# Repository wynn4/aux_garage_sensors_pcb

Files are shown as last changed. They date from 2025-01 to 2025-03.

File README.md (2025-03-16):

# *GarageGateGuard*
## About
This project contains KiCad 8.0 files and all supporting information needed for you to build your own *GarageGateGuard* PCB to protect the liftgate of your vehicle from having the garage door accidentally closed on it. The *GarageGateGuard* PCB enables you to add an auxiliary pair of infrared sensors to your garage door opening. When the auxiliary sensors are blocked (e.g., by your car's liftgate), power to the infrared transmitter of your opener's primary sensor pair is interrupted--emulating a blockage condition and stopping your opener from closing the door. Regular safety operation of your primary sensors is still maintained.

The PCB is built around a circuit presented by [@0033mer](https://youtube.com/@0033mer?si=xY0d-Dty4cxYaAsI) in a his "Garage Door Safety Sensors" [video](https://youtu.be/CdpjvQUqqL8?si=sJUc2Y0D_GqsPqLC) where he shows how to decode the output of the infrared receiver to determine if the beam from the transmitter is being received or not. In this PCB design, the decoded signal is used to control an NMOS switch which is wired up to control the ON-state of the garage opener's primary infrared transmitter. Full details can be seen in the included schematic and wiring diagram.

## Operation
For the auxiliary sensors, the PCB is designed to use a pair of 6V "universal" garage door safety sensors and has been validated using [these sensors](https://a.co/d/aTHSjK9) from Amazon. In theory the name-brand sensors from LiftMaster, Chamberlain, etc., should also work, but none of these have been tested. Because the system's "interface" with the existing garage door opener is so simple (i.e., just interrupting the ground connection to the opener's existing infrared transmitter), it should work with virtually any opener that has safety sensors powered by DC voltage under 40V (this is the Drain-Source voltage limit of the NMOS). The PCB reqires 6VDC supplied via J1 (see BOM for recommended power supply) and the PWR LED will illuminate to indicate the board is powered-on. When the auxiliary sensors (TXB and RXB) are not within line-of-sight of each other, the BLK (i.e., "blocked") LED will also illuminate. For the PCB to function as designed, a pin-jumper (see BOM) must be placed in the ACT (i.e., "active") position on JP1. If the PCB were to fail, or begin to malfunction, original operation of your garage door could be quickly restored by simply moving the jumper to the BYP (i.e., "bypass") position.

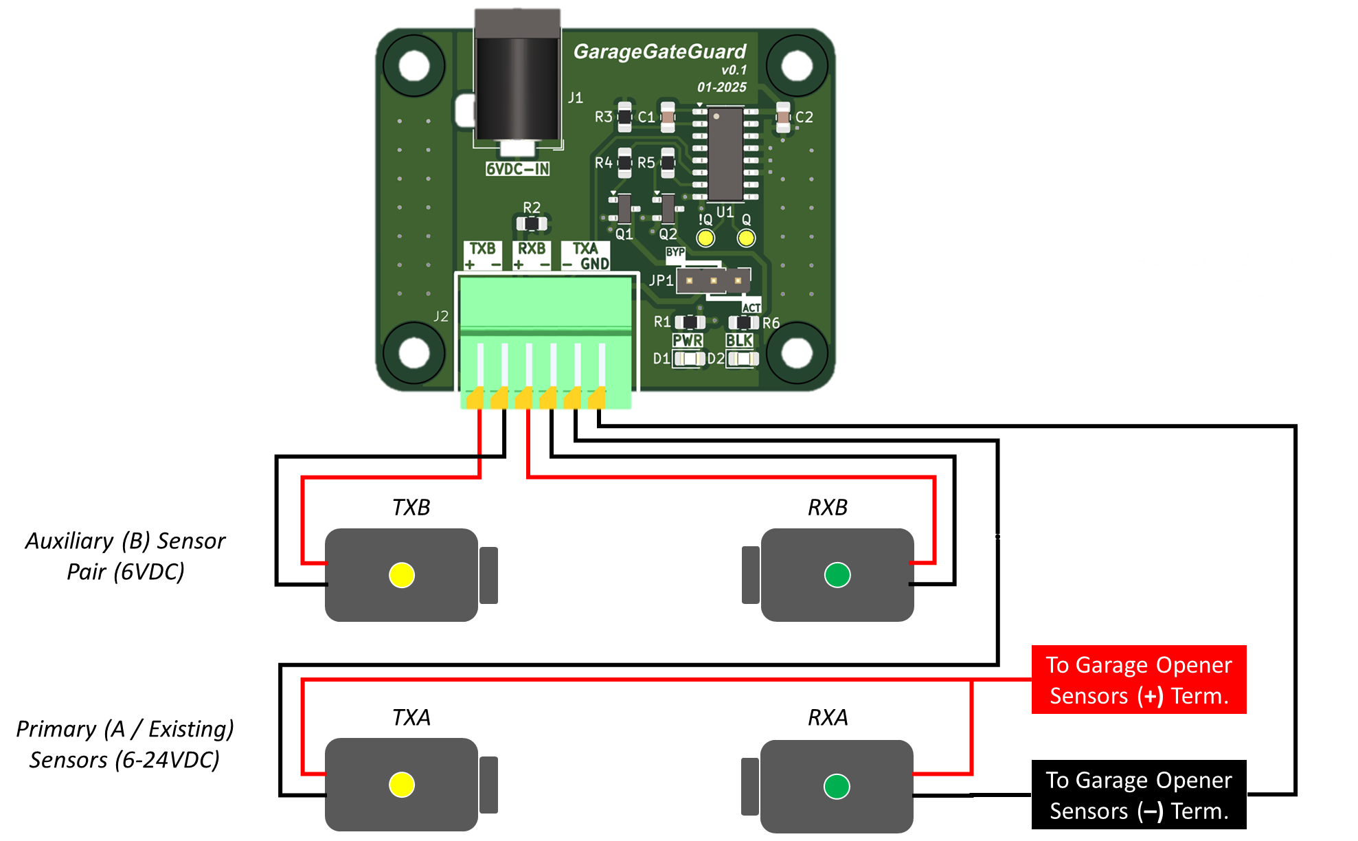
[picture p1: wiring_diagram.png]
wiring_diagram


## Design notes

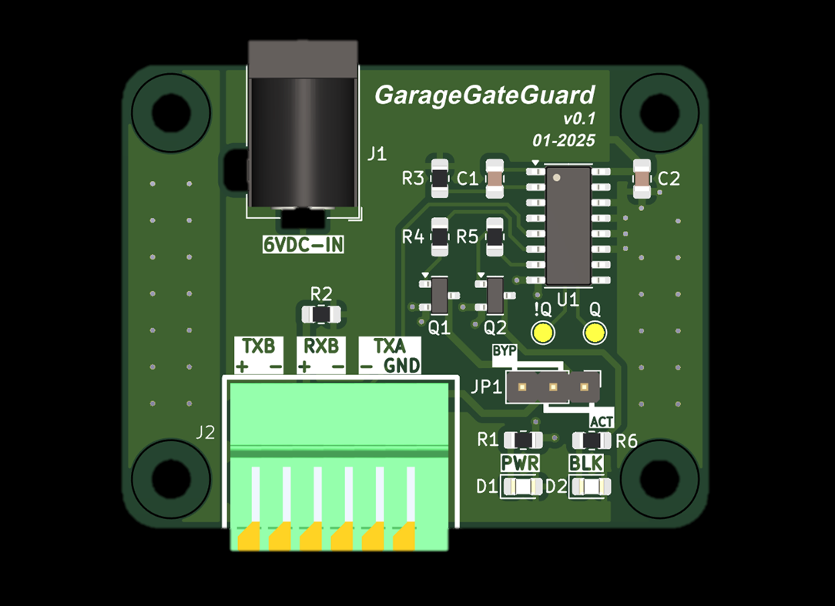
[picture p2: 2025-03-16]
render_v01.png

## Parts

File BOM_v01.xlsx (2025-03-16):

REF | MFR | MPN | QTY | DNI
C1, C2 | Samsung Electro-Mechanics | CL21B104KBCNNNC | 2 | 0
D1, D2 | Würth Elektronik | 150080AS75000 | 2 | 0
J1 | Same Sky (Formerly CUI Devices) | PJ-102AH | 1 | 0
J2 | Same Sky (Formerly CUI Devices) | TBL003-254-06GR-2OR | 1 | 0
JP1 | Würth Elektronik | 61300311121 | 1 | 0
Q1, Q2 | Infineon Technologies | IRLML0040TRPBF | 2 | 0
R1, R4-R6 | Stackpole Electronics Inc | RNCP0805FTD1K00 | 4 | 0
R2 | Panasonic Electronic Components | ERJ-P06J151V | 1 | 0
R3 | YAGEO | RC0805FR-07100KL | 1 | 0
U1 | Texas Instruments | CD14538BM96 | 1 | 0
PCB Post-Manufacturing Accessories
JP1-JP | Sullins Connector Solutions | QPC02SXGN-RC | 1 | 1
6V-PSU | XP Power | VEL05US060-US-JA | 1 | 1

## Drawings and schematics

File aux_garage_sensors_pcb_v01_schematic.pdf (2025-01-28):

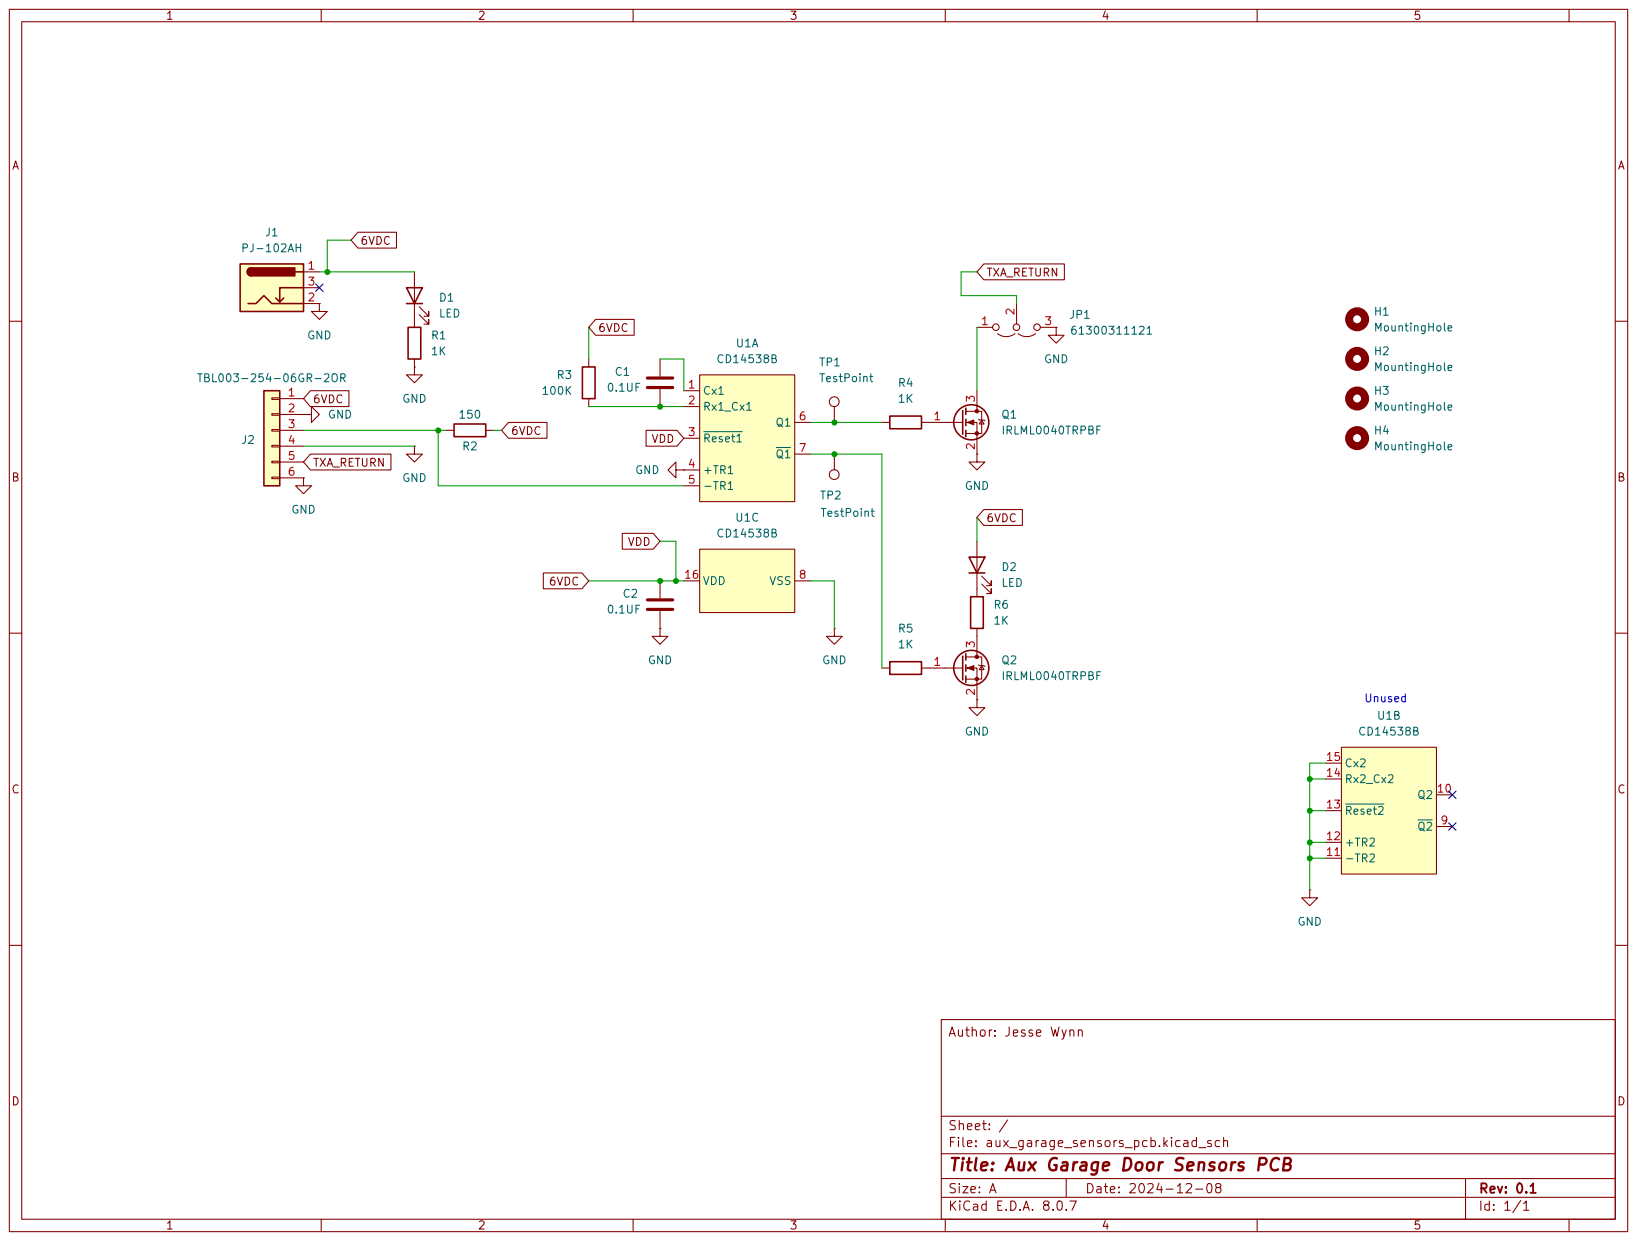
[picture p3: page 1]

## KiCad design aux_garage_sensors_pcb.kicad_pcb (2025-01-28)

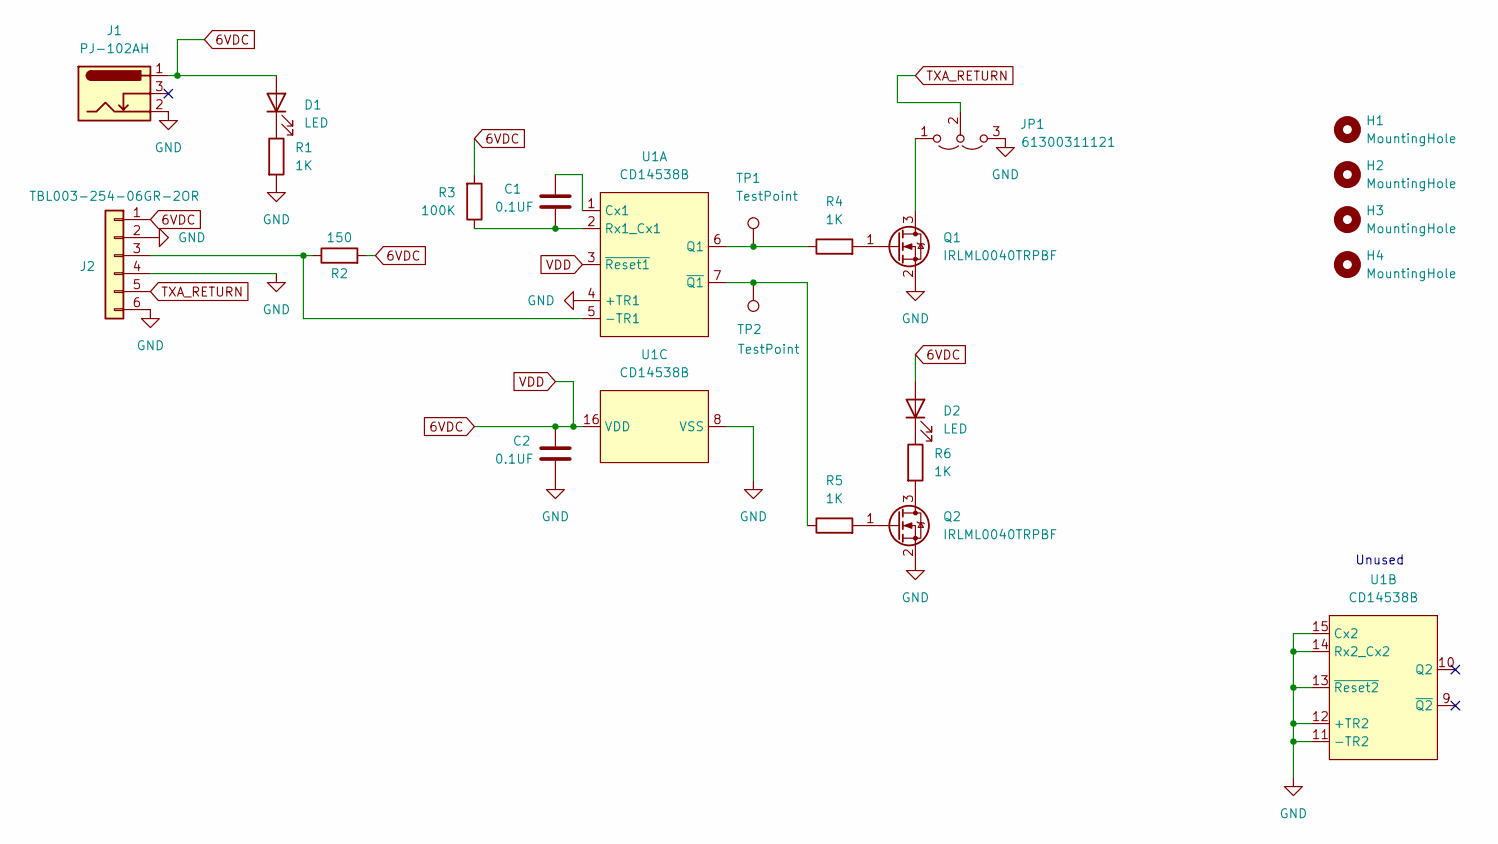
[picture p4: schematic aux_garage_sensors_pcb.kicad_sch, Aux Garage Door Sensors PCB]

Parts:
C1, C2: 0.1UF; C_0805_2012Metric_Pad1.18x1.45mm_HandSolder; MPN CL21B104KBCNNNC
D1, D2: LED; LED_0805_2012Metric_Pad1.15x1.40mm_HandSolder; MPN 150080AS75000
H1, H2, H3, H4: MountingHole; MountingHole_3.2mm_M3
J1: PJ-102AH; BarrelJack_Horizontal; MPN PJ-102AH
J2: TBL003-254-06GR-2OR; screwless_terminal_block_01x06; MPN TBL003-254-06GR-2OR
JP1: 61300311121; PinHeader_1x03_P2.54mm_Vertical; MPN 61300311121
Q1, Q2: IRLML0040TRPBF; SOT-23; MPN IRLML0040TRPBF
R1, R4, R5, R6: 1K; R_0805_2012Metric_Pad1.20x1.40mm_HandSolder; MPN RNCP0805FTD1K00
R2: 150; R_0805_2012Metric_Pad1.20x1.40mm_HandSolder; MPN ERJ-P06J151V
R3: 100K; R_0805_2012Metric_Pad1.20x1.40mm_HandSolder; MPN RC0805FR-07100KL
TP1, TP2: TestPoint; TestPoint_Pad_D1.5mm
U1: CD14538B; SOIC-16_3.9x9.9mm_P1.27mm; MPN CD14538BM96

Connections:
6VDC: C2.1, D1.2 (A), D2.2 (A), J1.1, J2.1, R2.2, R3.2, U1.3 (~Reset1), U1.16 (VDD)
GND: C2.2, J1.2, J2.2, J2.4, J2.6, JP1.3 (B), Q1.2 (S), Q2.2 (S), R1.2, U1.4 (+TR1), U1.8 (VSS), U1.11 (-TR2), U1.12 (+TR2), U1.13 (~Reset2), U1.14 (Rx2_Cx2), U1.15 (Cx2)
unnamed: D1.1 (K), R1.1
unnamed: D2.1 (K), R6.1
unnamed: J2.3, R2.1, U1.5 (-TR1)
unnamed: JP1.1 (A), Q1.3 (D)
unnamed: Q1.1 (G), R4.2
unnamed: Q2.3 (D), R6.2
unnamed: Q2.1 (G), R5.2
unnamed: C1.1, U1.1 (Cx1)
unnamed 10: R4.1, TP1.1, U1.6 (Q1); also elsewhere on the board
unnamed: C1.2, R3.1, U1.2 (Rx1_Cx1)
unnamed 12: R5.1, TP2.1, U1.7 (~Q1); also elsewhere on the board
TXA_RETURN: J2.5, JP1.2 (C)

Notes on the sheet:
Unused

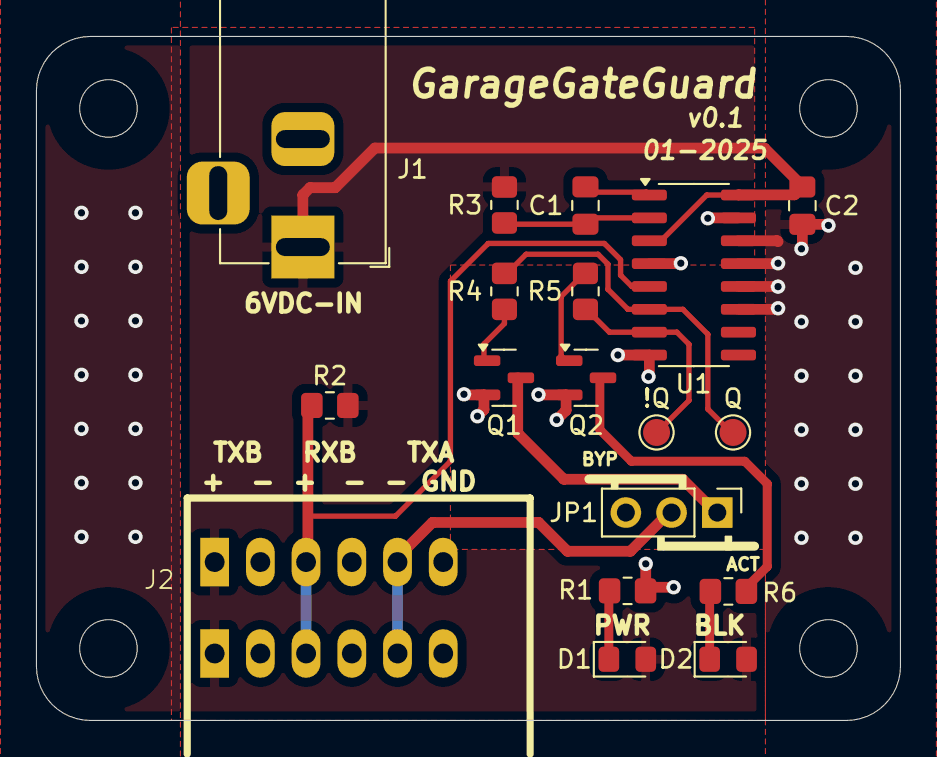
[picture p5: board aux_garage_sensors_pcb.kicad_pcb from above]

Board: 2 copper layers, 48.0 x 38.0 mm, 22 parts (0 on the bottom side), 14 nets.

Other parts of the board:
!Q: TestPoint; TestPoint_Pad_D1.5mm
Q: TestPoint; TestPoint_Pad_D1.5mm

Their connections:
unnamed 10: Q.1; also elsewhere on the board
unnamed 12: !Q.1; also elsewhere on the board

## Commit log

2025-01-27 adding initial project files
    [aux_garage_sensors_pcb.kicad_pcb, aux_garage_sensors_pcb.kicad_sch]
2025-01-27 added date and git info to silkscreen
    [aux_garage_sensors_pcb.kicad_pcb]
2025-01-28 added BOM and v0.1 manufacturing files
    [BOM_v01.xlsx, aux_garage_sensors_pcb.kicad_pcb]
2025-03-16 added README
    [BOM_v01.xlsx]
